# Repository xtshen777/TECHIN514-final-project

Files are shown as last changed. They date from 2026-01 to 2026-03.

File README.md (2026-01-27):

# Desk Emotion Indicator

## 1. Project overview

### Desk Emotion Indicator 
Cat-Ear Headband–based PPG Emotion Sensing System

### What it does  
The Desk Emotion Indicator is a two device system that uses a cat ear headband to measure heart related signals at the temples and a desk display with a mechanical gauge needle to visualize emotional trends from relaxed to stressed. The system is designed for desk based study or work, giving a calm and glanceable reflection of emotional state rather than exact numbers.

### General Sketch  
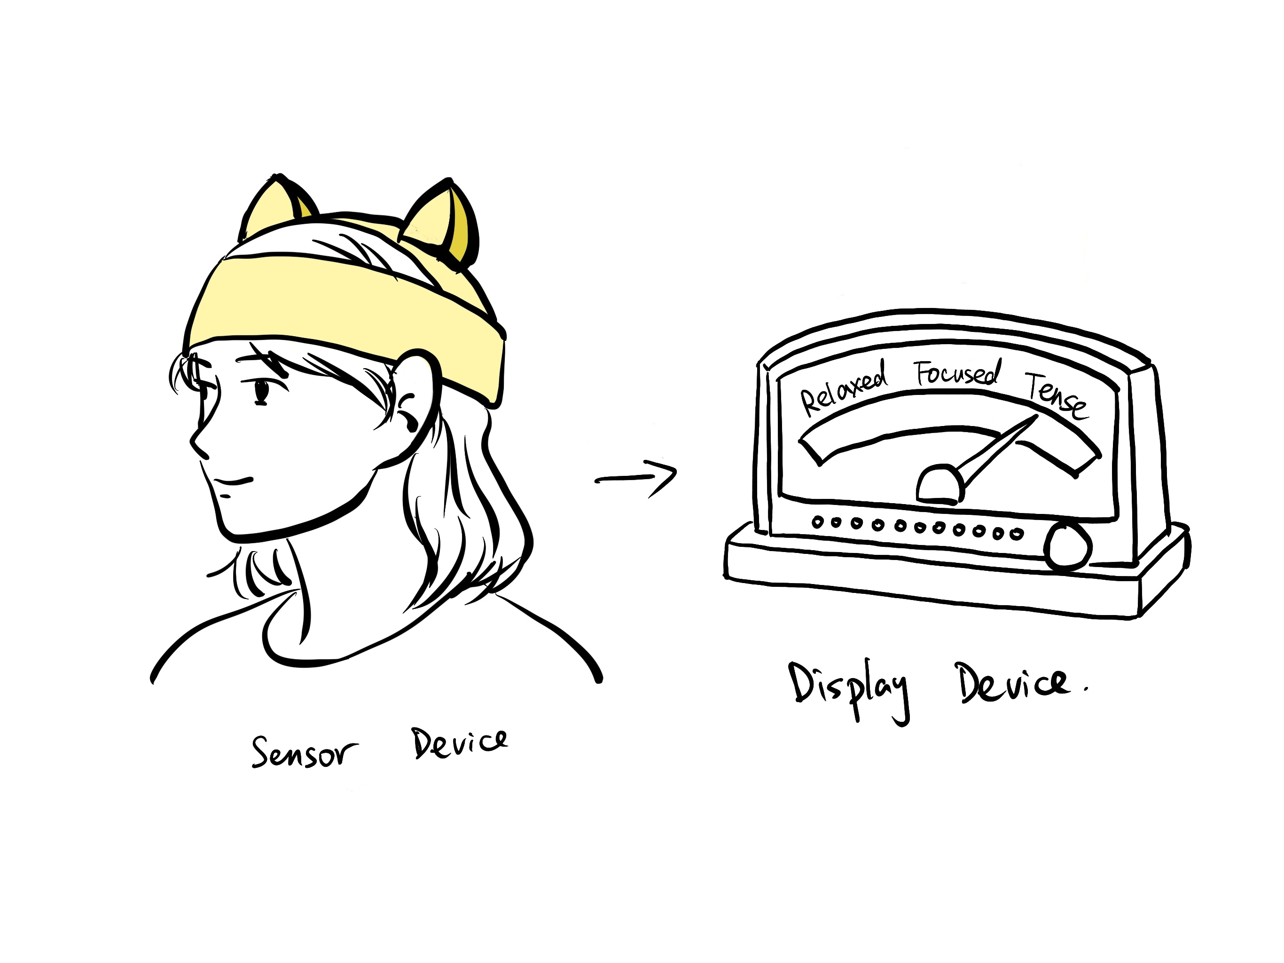
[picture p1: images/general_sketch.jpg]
Personal Safety Detector & Alarm Sketch

The sensing device is a cat shaped headband with two wide side sections that gently cover and touch the temple areas. A PPG sensor module is embedded inside each wide section so that the optical window rests against the skin, with soft foam pads and light blocking rings for comfort and signal quality. The cat ears on top of the headband are slightly thickened and used to hide the PCB, ESP32 based microcontroller and battery, as well as to route and organize the sensor wiring.

The display device is a small desk unit that looks like a vintage analog meter. It has a mechanical gauge needle driven by a stepper motor to show a continuous emotional state from relaxed to tense, a row of LEDs below the gauge as a secondary indication and a single reset or acknowledge button. The desk unit receives processed heart rate features wirelessly from the headband and updates the gauge and LEDs smoothly.

---

## 2. Sensor device (cat ear headband)

### Concept and placement  
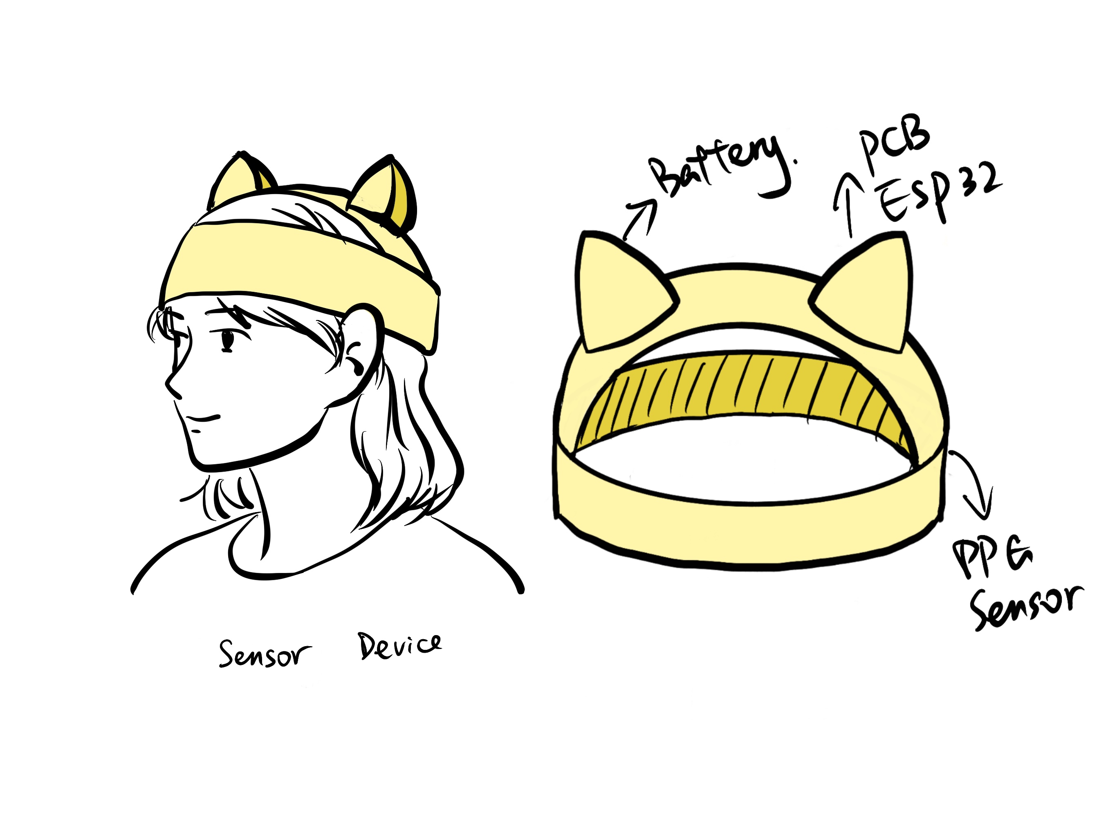
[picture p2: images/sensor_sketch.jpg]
Sensor Device

The sensor device is a cat ear headband that integrates PPG sensing modules at the temple positions. The headband sides are widened in the region that covers the temples to create space for the PPG boards and to provide a larger, more comfortable contact surface. On the inner side, soft foam pads and a small dark ring around each PPG window help maintain gentle pressure, reduce ambient light and improve signal quality. The cat ears on top of the headband are used as a functional enclosure that hides the main PCB, ESP32 module and battery, while also serving as a playful form language.

### Electronics and part numbers  
Planned parts for the sensor device include:

- Processor and wireless  
  - Seeed Studio XIAO ESP32C3 (ESP32 C3 based MCU with BLE)

- Optical heart sensor  
  - MAX30102 pulse oximeter and heart rate sensor module  
    - PPG sensing for heart rate and heart rate variability features  
  - Initially one MAX30102 module at one temple for prototyping, with the option to extend to both sides later

- Power  
  - 3.7 V LiPo battery, about 500 mAh  
  - TP4056 LiPo charger module  
  - Power switch

- Mechanical and wiring  
  - Cat ear headband shell with widened temple sections  
  - Soft foam or silicone pads around each sensor window  
  - Flexible wires routed inside the headband structure  
  - Custom small PCB in one cat ear that connects MAX30102, XIAO ESP32C3, battery and charger

### How it works  
The MAX30102 module in the temple section emits light into the skin and measures the reflected light signal that changes with blood volume. The Seeed XIAO ESP32C3 reads raw PPG samples over I2C, applies basic filtering and peak detection and computes heart rate and short term heart rate variability features over a sliding time window. Instead of sending raw signals, the headband computes compact emotional features such as smoothed heart rate and an HRV based stress score and periodically transmits these features via BLE to the desk display device. The headband is designed for stable contact during desk work, avoiding hand and wrist motion artifacts.

---

## 3. Display device (desk gauge)

### Concept and placement  
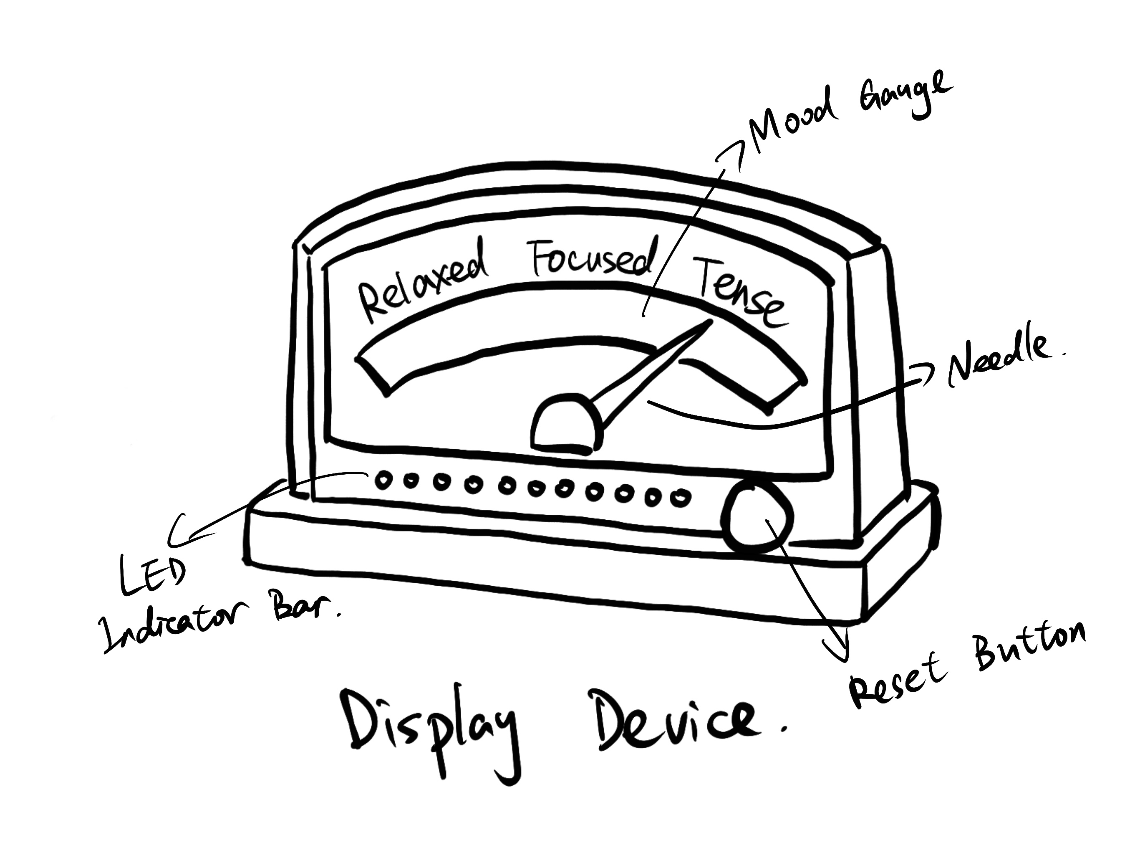
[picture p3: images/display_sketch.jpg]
Display Device

The display device is a compact desk unit that turns the incoming physiological features into a physical gauge and subtle light feedback. The main element is a mechanical needle gauge that moves smoothly between relaxed and stressed states. Below the gauge, a horizontal row of LEDs provides a secondary visualization that lights up more segments as the user becomes more tense. A single tactile button on the front allows the user to reset or acknowledge the current state or recalibrate the baseline.

### Electronics and part numbers  
Planned parts for the display device include:

- Processor and wireless  
  - Seeed Studio XIAO ESP32C3 (second board, acting as BLE central and display controller)

- Mechanical gauge  
  - 28BYJ 48 stepper motor  
  - ULN2003 stepper motor driver board

- Visual indicators  
  - LEDs, green, yellow and red or several identical color LEDs  
  - Current limiting resistors for each LED (for example 220 Ω to 330 Ω)

- User input  
  - One momentary tactile push button for reset or acknowledge

- Power  
  - 3.7 V LiPo battery, about 1000 mAh  
  - TP4056 LiPo charger module  
  - Power switch

- Mechanical  
  - Custom enclosure designed to sit on a desk and support the gauge dial  
  - Custom PCB that connects XIAO ESP32C3, ULN2003, LEDs, button and power components

### How it works  
The desk device acts as a BLE central and listens for periodic data packets from the headband sensor device. When it receives new heart rate and HRV based features, the XIAO ESP32C3 maps the emotional state score to a target gauge angle and LED pattern. The microcontroller drives the ULN2003 board to step the 28BYJ 48 motor to the new angle in a smooth way to avoid sudden jumps. The LEDs under the gauge are updated to indicate low, medium or high stress zones. The reset button allows the user to set a new baseline or clear a previously high state. The display is intentionally quiet and uses only motion and soft light to keep the feedback calm and ambient.

---

## 4. System communication and diagrams

### 4.1 High level system diagram
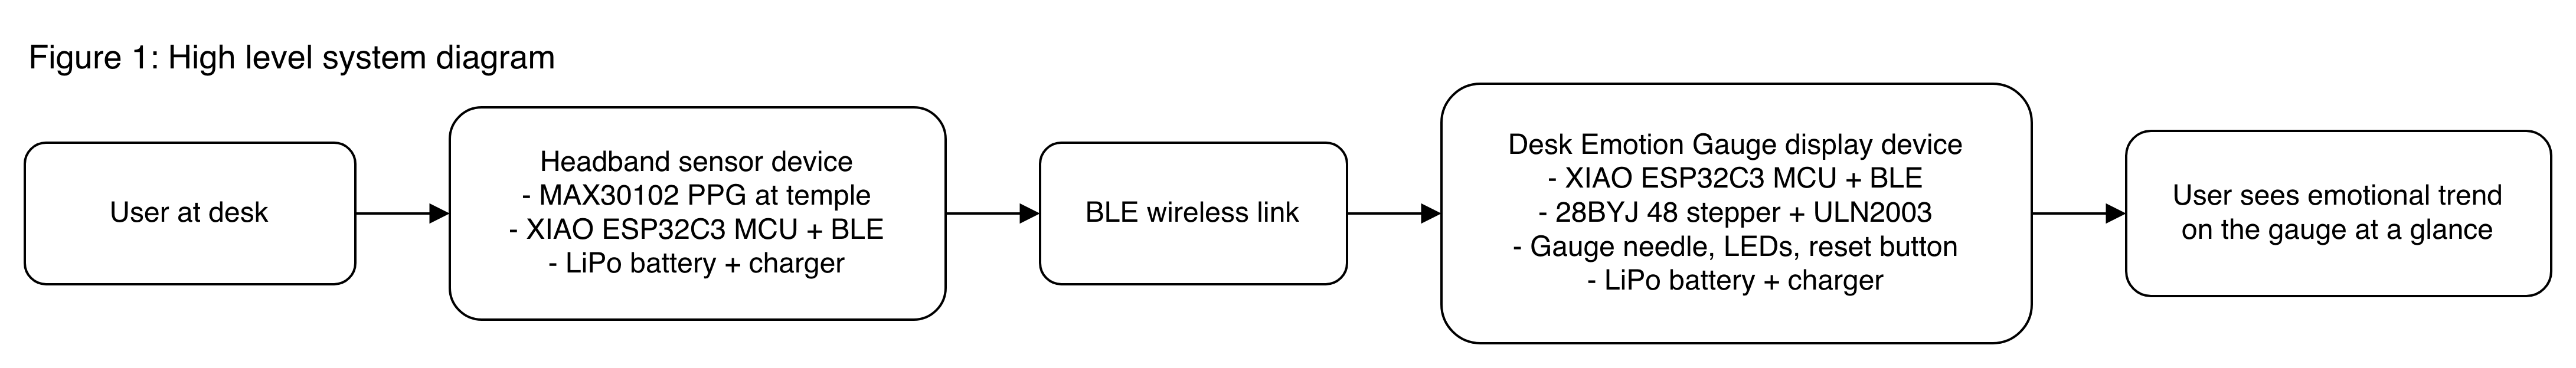
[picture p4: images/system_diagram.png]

- User sitting at a desk wearing the cat ear headband  
- The cat ear headband labeled as "Sensor device" with temple based PPG sensing  
- The desk gauge unit labeled as "Display device" with needle, LEDs and button  
- A BLE wireless link between headband and desk gauge  

### 4.2 Detailed data flow diagram (figure 2)
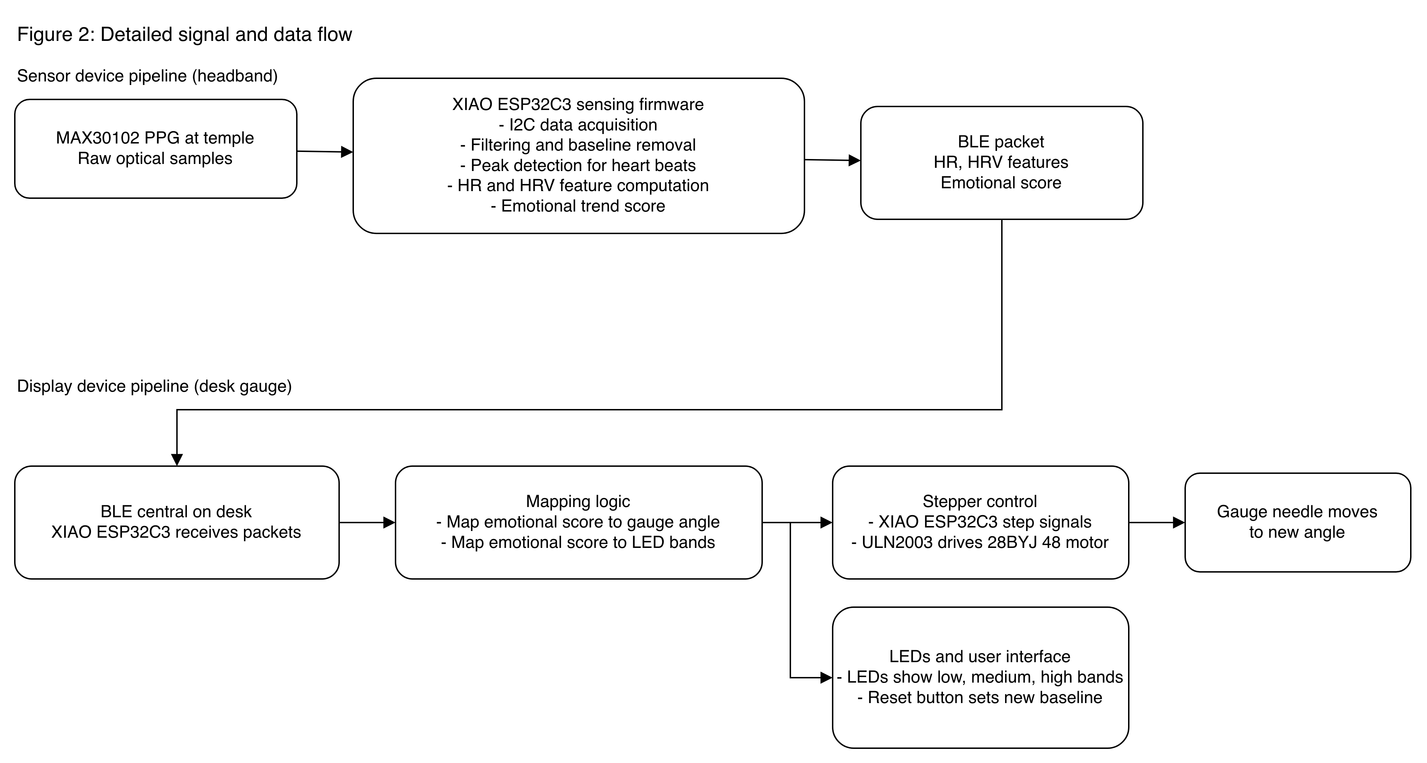
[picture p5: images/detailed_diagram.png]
 

Sensor device pipeline (headband):

- MAX30102 PPG module at temple  
  - Raw optical signal samples  
- XIAO ESP32C3 sensing firmware  
  - I2C data acquisition  
  - Filtering and baseline removal  
  - Peak detection for heart beats  
  - Heart rate and HRV feature computation  
  - Emotional trend score calculation  
- BLE packet  
  - Contains heart rate, HRV features and an emotional score  

Display device pipeline (desk gauge):

- BLE central on desk XIAO ESP32C3  
  - Receives packets from the headband  
- Mapping logic  
  - Map emotional score to gauge angle range  
  - Map emotional score to LED band states  
- Stepper control  
  - XIAO ESP32C3 generates step signals  
  - ULN2003 driver powers 28BYJ 48 motor  
  - Gauge needle moves to new angle  
- LED and user interface  
  - LEDs show low, medium or high emotional bands  
  - User can press the reset button to set a new baseline or acknowledge a high state  

---

## 5. Datasheets

All component datasheets used in this project are available in the `datasheets/` folder:

- [Seeed XIAO ESP32C3](datasheets/Seeed_XIAO_ESP32C3.pdf)
- [MAX30102 PPG Sensor](datasheets/MAX30102_sensor.pdf)
- [28BYJ-48 Stepper Motor](datasheets/28BYJ48_stepper_motor.pdf)
- [ULN2003 Driver](datasheets/ULN2003_driver.pdf)
- [TP4056 Charger](datasheets/TP4056_charger.pdf)
- [LiPo Battery](datasheets/LiPo_battery.pdf)
- [Tactile Switch](datasheets/tactile_switch.pdf)
- [NeoPixel Digital RGB LED Strip](datasheets/NeoPixel_LED.pdf)

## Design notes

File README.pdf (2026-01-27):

README.md | 2026-01-26

# Desk Emotion Indicator

## 1. Project overview

Desk Emotion Indicator

Cat-Ear Headband–based PPG Emotion Sensing System

What it does

The Desk Emotion Indicator is a two device system that uses a cat ear headband to measure heart related signals at the temples and a desk display with a mechanical gauge needle to visualize emotional trends from relaxed to stressed. The system is designed for desk based study or work, giving a calm and glanceable reflection of emotional state rather than exact numbers.

General Sketch


The sensing device is a cat shaped headband with two wide side sections that gently cover and touch the temple areas. A PPG sensor module is embedded inside each wide section so that the optical window rests against the skin, with soft foam pads and light blocking rings for comfort and signal quality. The cat ears on top of the headband are slightly thickened and used to hide the PCB, ESP32 based microcontroller and battery, as well as to route and organize the sensor wiring.

The display device is a small desk unit that looks like a vintage analog meter. It has a mechanical gauge needle driven by a stepper motor to show a continuous emotional state from relaxed to tense, a row of LEDs below the gauge as a secondary indication and a single reset or acknowledge button. The desk unit receives processed heart rate features wirelessly from the headband and updates the gauge and LEDs smoothly.

## 2. Sensor device (cat ear headband)

Concept and placement


The sensor device is a cat ear headband that integrates PPG sensing modules at the temple positions. The headband sides are widened in the region that covers the temples to create space for the PPG boards and to provide a larger, more comfortable contact surface. On the inner side, soft foam pads and a small dark ring around each PPG window help maintain gentle pressure, reduce ambient light and improve signal quality. The cat ears on top of the headband are used as a functional enclosure that hides the main PCB, ESP32 module and battery, while also serving as a playful form language.

Electronics and part numbers

Planned parts for the sensor device include:

Processor and wireless

Seeed Studio XIAO ESP32C3 (ESP32 C3 based MCU with BLE)

Optical heart sensor

MAX30102 pulse oximeter and heart rate sensor module
PPG sensing for heart rate and heart rate variability features
Initially one MAX30102 module at one temple for prototyping, with the option to extend to both sides later

Power

3.7 V LiPo battery, about 500 mAh TP4056 LiPo charger module Power switch

Mechanical and wiring

Cat ear headband shell with widened temple sections
Soft foam or silicone pads around each sensor window
Flexible wires routed inside the headband structure
Custom small PCB in one cat ear that connects MAX30102, XIAO ESP32C3, battery and charger

How it works

The MAX30102 module in the temple section emits light into the skin and measures the reflected light signal that changes with blood volume. The Seeed XIAO ESP32C3 reads raw PPG samples over I2C, applies basic filtering and peak detection and computes heart rate and short term heart rate variability features over a sliding time window. Instead of sending raw signals, the headband computes compact emotional features such as smoothed heart rate and an HRV based stress score and periodically transmits these features via BLE to the desk display device. The headband is designed for stable contact during desk work, avoiding hand and wrist motion artifacts.

## 3. Display device (desk gauge)

Concept and placement


The display device is a compact desk unit that turns the incoming physiological features into a physical gauge and subtle light feedback. The main element is a mechanical needle gauge that moves smoothly between relaxed and stressed states. Below the gauge, a horizontal row of LEDs provides a secondary visualization that lights up more segments as the user becomes more tense. A single tactile button on the front allows the user to reset or acknowledge the current state or recalibrate the baseline.

Electronics and part numbers

Planned parts for the display device include:

Processor and wireless

Seeed Studio XIAO ESP32C3 (second board, acting as BLE central and display controller)

Mechanical gauge

28BYJ 48 stepper motor
ULN2003 stepper motor driver board

Visual indicators

LEDs, green, yellow and red or several identical color LEDs
Current limiting resistors for each LED (for example 220 Ω to 330 Ω)

User input

One momentary tactile push button for reset or acknowledge

Power

3.7 V LiPo battery, about 1000 mAh
TP4056 LiPo charger module Power switch

Mechanical

Custom enclosure designed to sit on a desk and support the gauge dial
Custom PCB that connects XIAO ESP32C3, ULN2003, LEDs, button and power components

How it works

The desk device acts as a BLE central and listens for periodic data packets from the headband sensor device. When it receives new heart rate and HRV based features, the XIAO ESP32C3 maps the emotional state score to a target gauge angle and LED pattern. The microcontroller drives the ULN2003 board to step the 28BYJ 48 motor to the new angle in a smooth way to avoid sudden jumps. The LEDs under the gauge are updated to indicate low, medium or high stress zones. The reset button allows the user to set a new baseline or clear a previously high state. The display is intentionally quiet and uses only motion and soft light to keep the feedback calm and ambient.

## 4. System communication and diagrams

4.1 High level system diagram

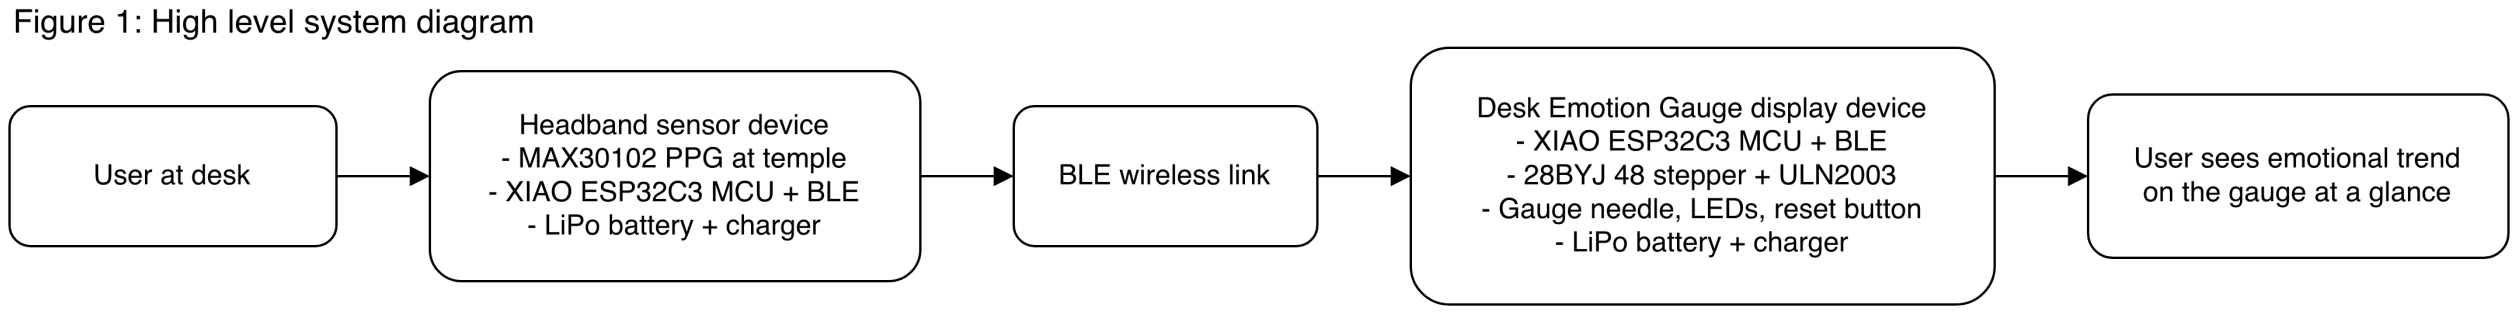
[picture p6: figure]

User sitting at a desk wearing the cat ear headband
The cat ear headband labeled as "Sensor device" with temple based PPG sensing The desk gauge unit labeled as "Display device" with needle, LEDs and button
A BLE wireless link between headband and desk gauge

4.2 Detailed data flow diagram (figure 2)

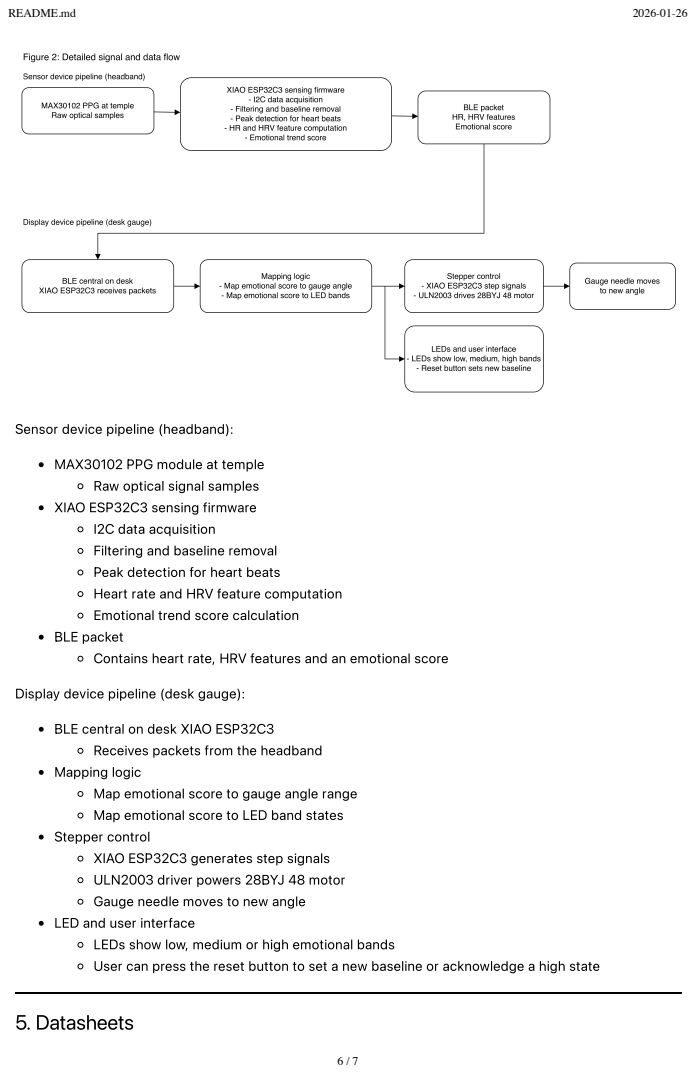
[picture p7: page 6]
5. Datasheets

Sensor device pipeline (headband):

MAX30102 PPG module at temple
Raw optical signal samples
XIAO ESP32C3 sensing firmware
I2C data acquisition
Filtering and baseline removal
Peak detection for heart beats
Heart rate and HRV feature computation
Emotional trend score calculation
BLE packet
Contains heart rate, HRV features and an emotional score

Display device pipeline (desk gauge):

BLE central on desk XIAO ESP32C3
Receives packets from the headband
Mapping logic
Map emotional score to gauge angle range
Map emotional score to LED band states
Stepper control
XIAO ESP32C3 generates step signals
ULN2003 driver powers 28BYJ 48 motor
Gauge needle moves to new angle
LED and user interface
LEDs show low, medium or high emotional bands
User can press the reset button to set a new baseline or acknowledge a high state

All component datasheets used in this project are available in the datasheets/ folder:

Seeed XIAO ESP32C3
MAX30102 PPG Sensor
28BYJ-48 Stepper Motor
ULN2003 Driver
TP4056 Charger
LiPo Battery
Tactile Switch
NeoPixel Digital RGB LED Strip

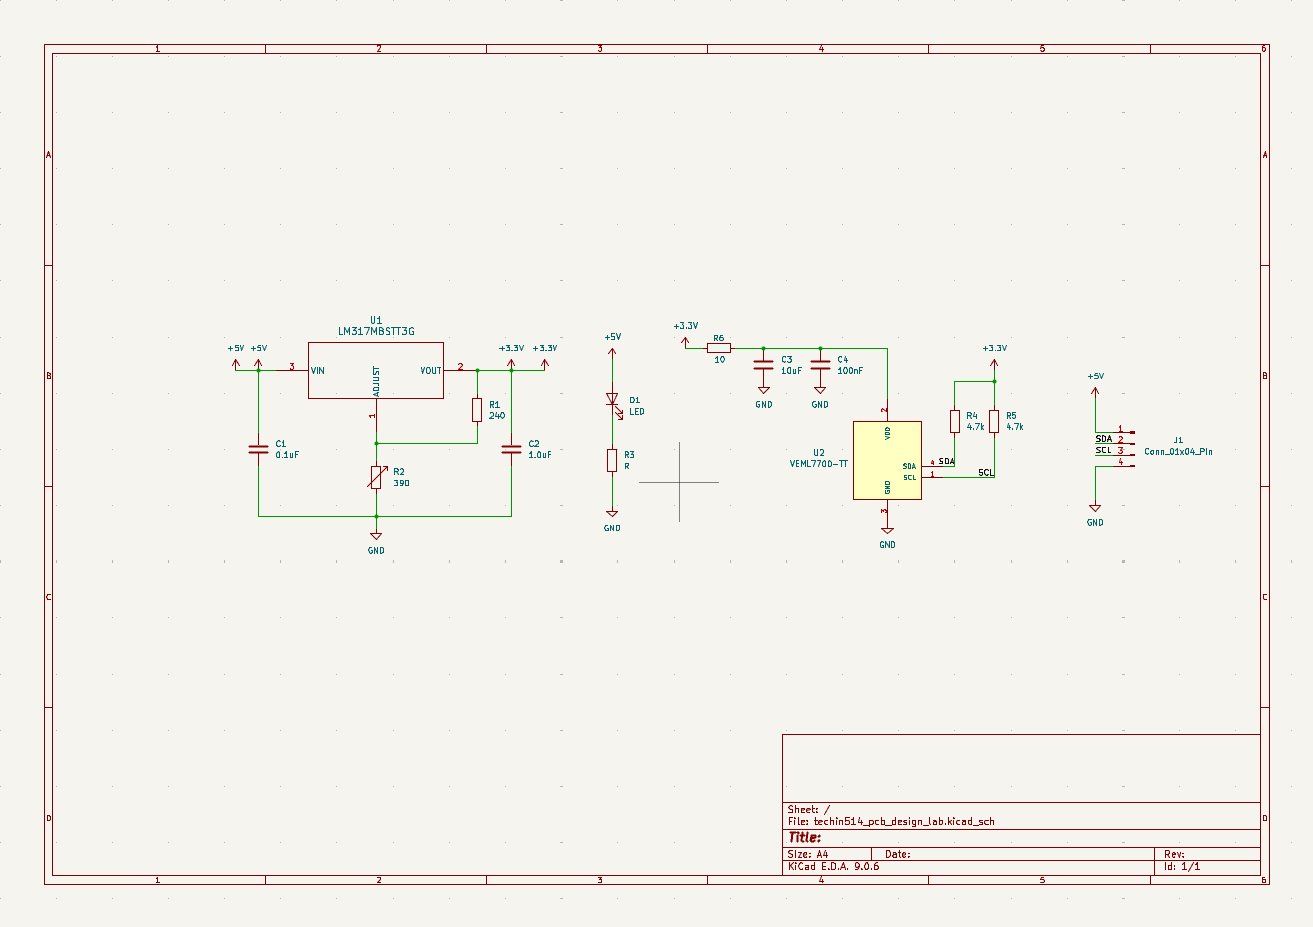
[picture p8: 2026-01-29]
pcb_lab/schematics.png

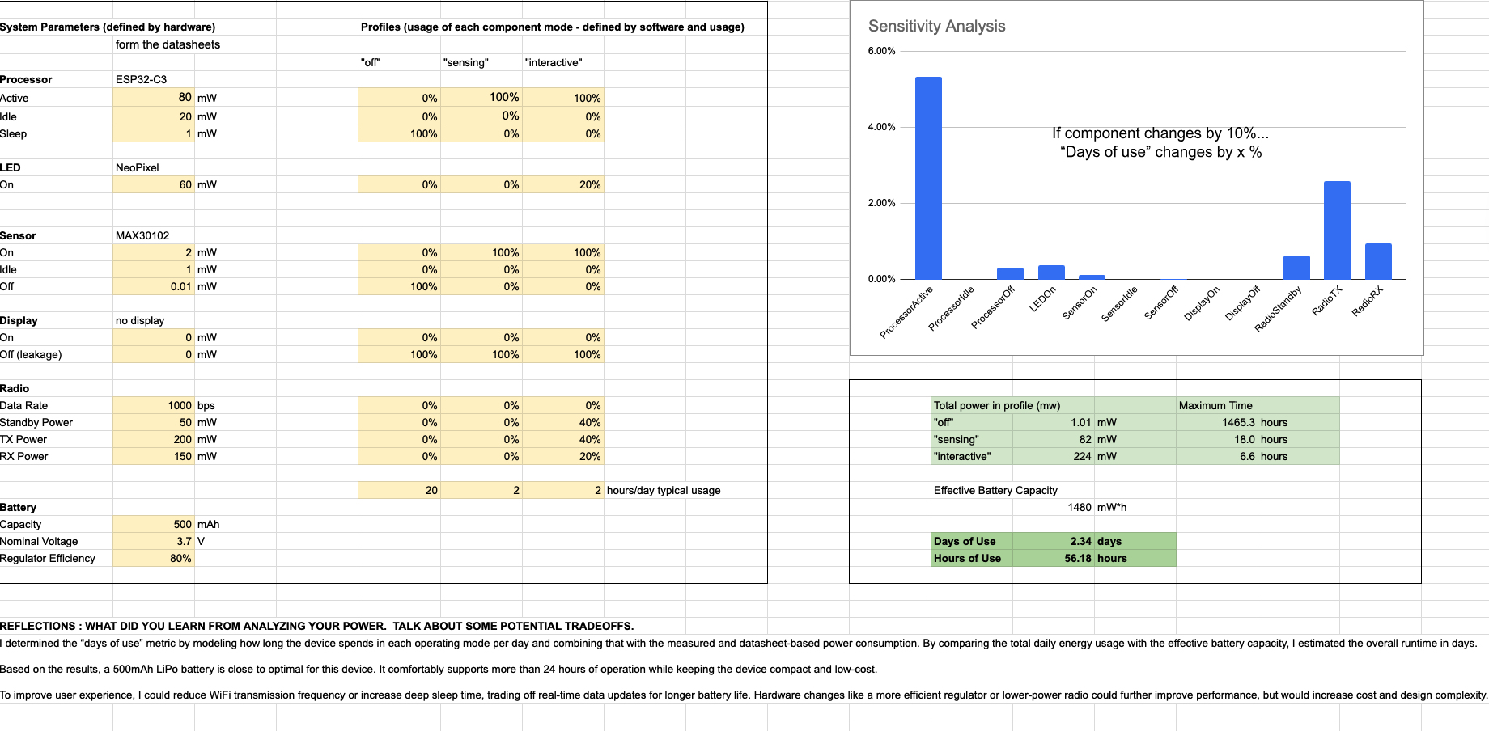
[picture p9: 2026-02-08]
battery_life_estimate/spreadsheet.png

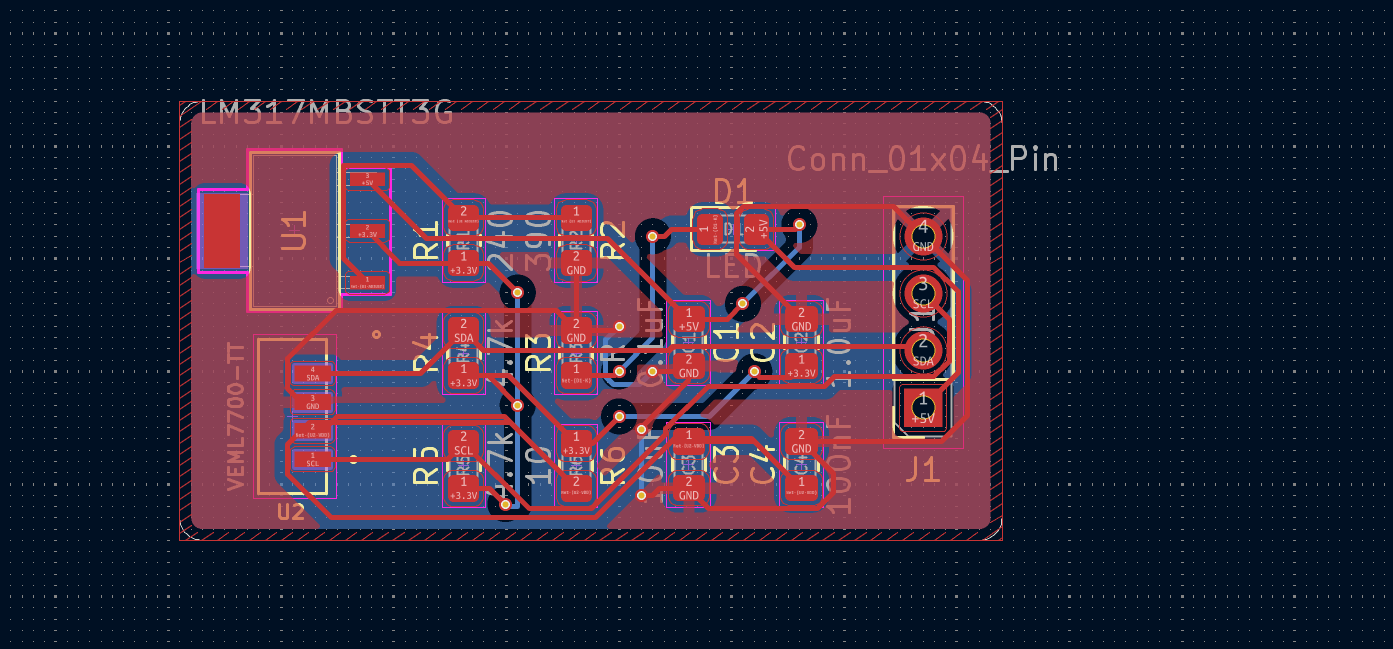
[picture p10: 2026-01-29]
pcb_lab/board layout.png

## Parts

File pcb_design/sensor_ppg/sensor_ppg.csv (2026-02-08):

# | Reference | Qty | Value | Footprint | DNP
1 | C1 | 1 | 10uF | Capacitor_SMD:C_0603_1608Metric_Pad1.08x0.95mm_HandSolder
2 | C2, C4 | 2 | 0.1uF | Capacitor_SMD:C_0603_1608Metric_Pad1.08x0.95mm_HandSolder
3 | C3 | 1 | 4.7uF | Capacitor_SMD:C_0603_1608Metric_Pad1.08x0.95mm_HandSolder
4 | C5, C6 | 2 | 1uF | Capacitor_SMD:C_0603_1608Metric_Pad1.08x0.95mm_HandSolder
5 | J1 | 1 | Conn_01x07_Pin | Connector_PinSocket_2.54mm:PinSocket_1x07_P2.54mm_Vertical
6 | R1, R2, R3 | 3 | 4.7kΩ | Resistor_SMD:R_0603_1608Metric_Pad0.98x0.95mm_HandSolder
7 | U1 | 1 | MAX30102EFD_T | MAX30102EFD_T:XDCR_MAX30101EFD_
8 | U2 | 1 | MIC5365-1.8YMT-TZ | MIC5365_1_8YMT_TZ_snap:VREG_MIC5365-1.8YMT-TZ

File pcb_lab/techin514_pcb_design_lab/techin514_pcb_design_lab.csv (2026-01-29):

# | Reference | Qty | Value | Footprint | DNP
1 | C1 | 1 | 0.1uF | Capacitor_SMD:C_0805_2012Metric_Pad1.18x1.45mm_HandSolder
2 | C2 | 1 | 1.0uF | Capacitor_SMD:C_0805_2012Metric_Pad1.18x1.45mm_HandSolder
3 | C3 | 1 | 10uF | Capacitor_SMD:C_0805_2012Metric_Pad1.18x1.45mm_HandSolder
4 | C4 | 1 | 100nF | Capacitor_SMD:C_0805_2012Metric_Pad1.18x1.45mm_HandSolder
5 | D1 | 1 | LED | LED_SMD:LED_0805_2012Metric_Pad1.15x1.40mm_HandSolder
6 | J1 | 1 | Conn_01x04_Pin | Connector_PinSocket_2.54mm:PinSocket_1x04_P2.54mm_Vertical
7 | R1 | 1 | 240 | Resistor_SMD:R_0805_2012Metric_Pad1.20x1.40mm_HandSolder
8 | R2 | 1 | 390 | Resistor_SMD:R_0805_2012Metric_Pad1.20x1.40mm_HandSolder
9 | R3 | 1 | R | Resistor_SMD:R_0805_2012Metric_Pad1.20x1.40mm_HandSolder
10 | R4, R5 | 2 | 4.7k | Resistor_SMD:R_0805_2012Metric_Pad1.20x1.40mm_HandSolder
11 | R6 | 1 | 10 | Resistor_SMD:R_0805_2012Metric_Pad1.20x1.40mm_HandSolder
12 | U1 | 1 | LM317MBSTT3G | footprints:SOT223-3_ONS
13 | U2 | 1 | VEML7700-TT | VEML7700_TT:XDCR_VEML7700-TT

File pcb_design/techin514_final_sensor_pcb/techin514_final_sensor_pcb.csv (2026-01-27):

# | Reference | Qty | Value | Footprint | DNP
1 | C1, C2, C3 | 3 | C
2 | D1 | 1 | LED
3 | D2 | 1 | NeoPixel Digital RGB LED | LED_SMD:LED_WS2812_PLCC6_5.0x5.0mm_P1.6mm
4 | M1 | 1 | Stepper_Motor_bipolar
5 | R1, R2, R3, R4, R5, R6 | 6 | R
6 | S1 | 1 | SWITCH
7 | U1 | 1 | MAX30102 | OptoDevice:Maxim_OLGA-14_3.3x5.6mm_P0.8mm
8 | U2 | 1 | MOUDLE-SEEEDUINO-XIAO-ESP32C3 | MOUDLE14P-SMD-2.54-21X17.8MM
9 | U3 | 1 | ULN2003
10 | U4 | 1 | LM317L_SOT-89 | Package_TO_SOT_SMD:SOT-89-3

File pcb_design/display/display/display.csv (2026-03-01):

# | Reference | Qty | Value | Footprint | DNP
1 | C1 | 1 | 10uF | Capacitor_SMD:C_0805_2012Metric_Pad1.18x1.45mm_HandSolder
2 | C2 | 1 | 0.01uF | Capacitor_SMD:C_0805_2012Metric_Pad1.18x1.45mm_HandSolder
3 | C3 | 1 | 2.2uF | Capacitor_SMD:C_0805_2012Metric_Pad1.18x1.45mm_HandSolder
4 | C4 | 1 | 100uF | Capacitor_SMD:C_0805_2012Metric_Pad1.18x1.45mm_HandSolder
5 | J1 | 1 | Conn_01x03 | Connector_JST:JST_PH_B3B-PH-K_1x03_P2.00mm_Vertical
6 | J2 | 1 | Conn_01x02 | Connector_JST:JST_PH_B2B-PH-K_1x02_P2.00mm_Vertical
7 | M1 | 1 | Stepper_Motor_bipolar | x27_Footprint:x27_stepper_two_holes
8 | R1, R2 | 2 | 0.2Ω | Resistor_SMD:R_0805_2012Metric_Pad1.20x1.40mm_HandSolder
9 | R3 | 1 | 330Ω | Resistor_SMD:R_0805_2012Metric_Pad1.20x1.40mm_HandSolder
10 | R4 | 1 | 10 kΩ | Resistor_SMD:R_0805_2012Metric_Pad1.20x1.40mm_HandSolder
11 | U1 | 1 | DRV8833PWR | DRV8833PWR:PW16_TEX-L
12 | U2 | 1 | XIAO ESP32C3 | GIX_ESP32:XIAO_ESP32

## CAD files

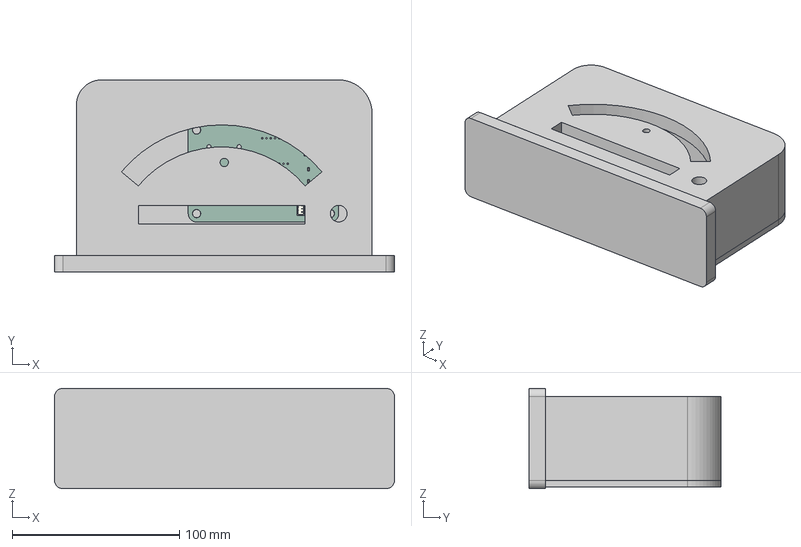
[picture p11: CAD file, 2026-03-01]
enclosure/display.step
203.4 x 115.0 x 60.0 mm
R_0805_2012Metric x 4
C_0805_2012Metric x 4
JST_PH_B3B-PH-K_1x03_P2.00mm_Vertical
JST_PH_B2B-PH-K_1x02_P2.00mm_Vertical
display_PCB

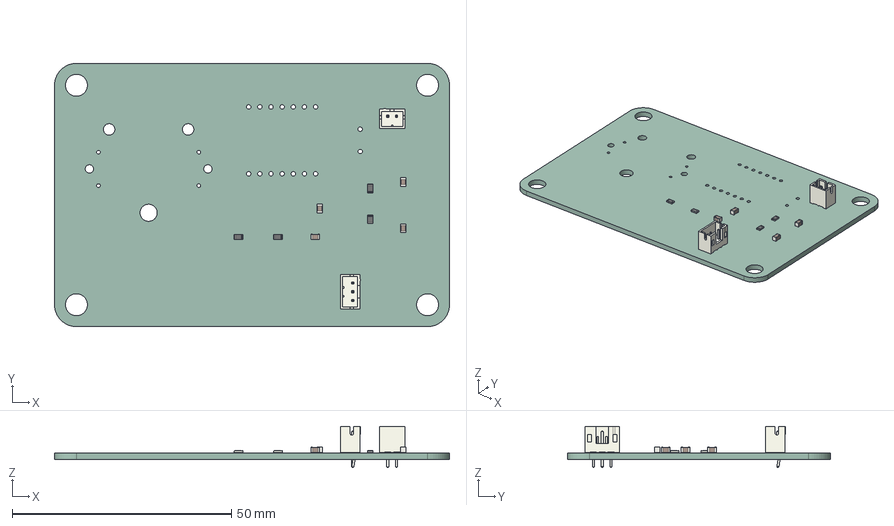
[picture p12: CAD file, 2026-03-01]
pcb_design/display/display/display.step
90.0 x 60.0 x 9.40 mm
R_0805_2012Metric x 4
C_0805_2012Metric x 4
JST_PH_B3B-PH-K_1x03_P2.00mm_Vertical
JST_PH_B2B-PH-K_1x02_P2.00mm_Vertical
display_PCB

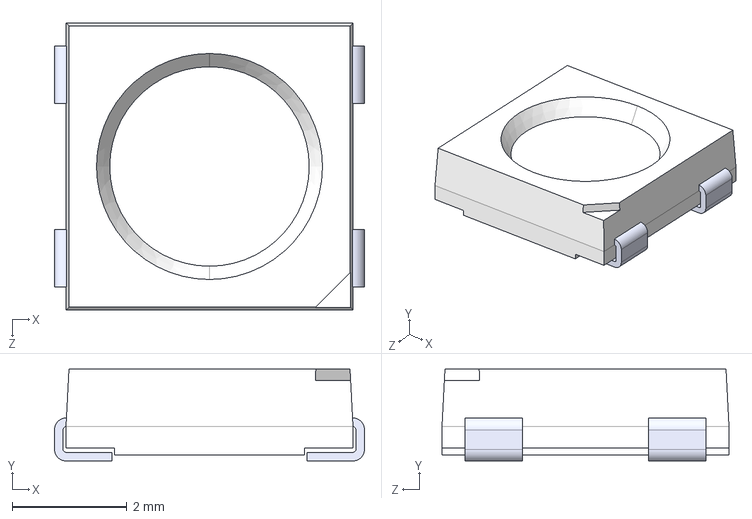
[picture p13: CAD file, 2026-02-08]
pcb_design/models/1655/1655.step
5.40 x 1.60 x 5.00 mm

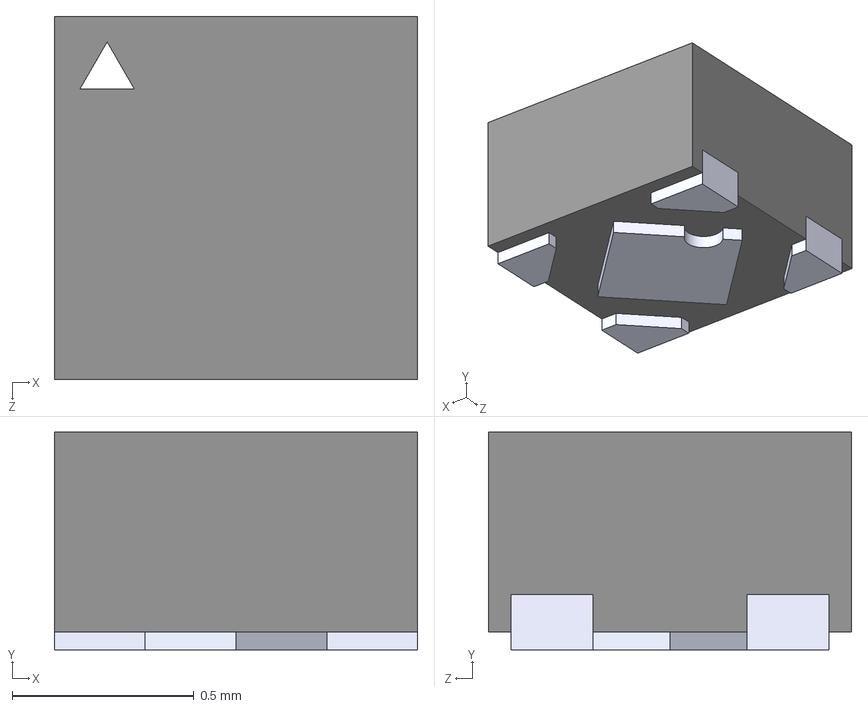
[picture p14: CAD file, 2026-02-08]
pcb_design/models/MIC5365_1_8YMT_TZ_snap/MIC5365-1.8YMT-TZ.step
1.00 x 0.6 x 1.00 mm

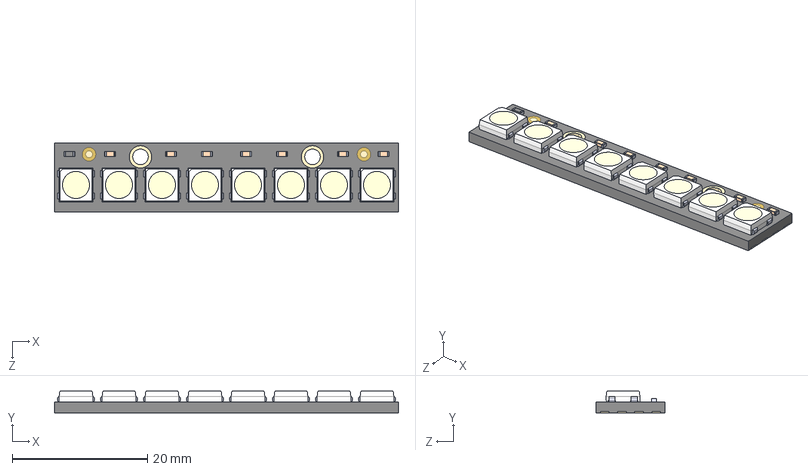
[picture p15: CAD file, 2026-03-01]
pcb_design/models/neopixel1426/1426.step
50.8 x 3.19 x 10.2 mm
1426 board
WS2812B--3DModel-STEP-510211 x 8
CAP_black
CAP_RC0603JR-073K3P x 7

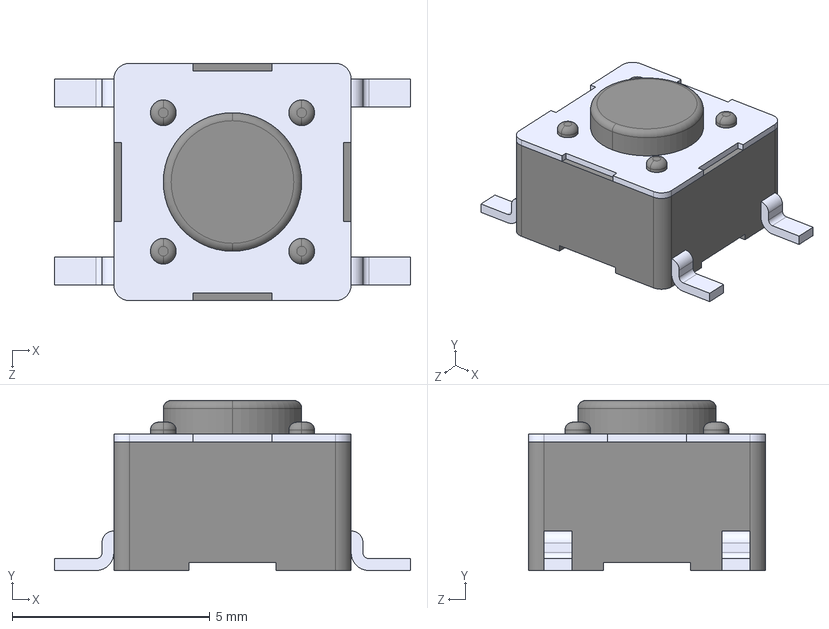
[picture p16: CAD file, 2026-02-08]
pcb_design/models/PTS645SK43SMTR92_LFS/PTS645SK43SMTR92LFS.step
9.00 x 4.30 x 6.00 mm

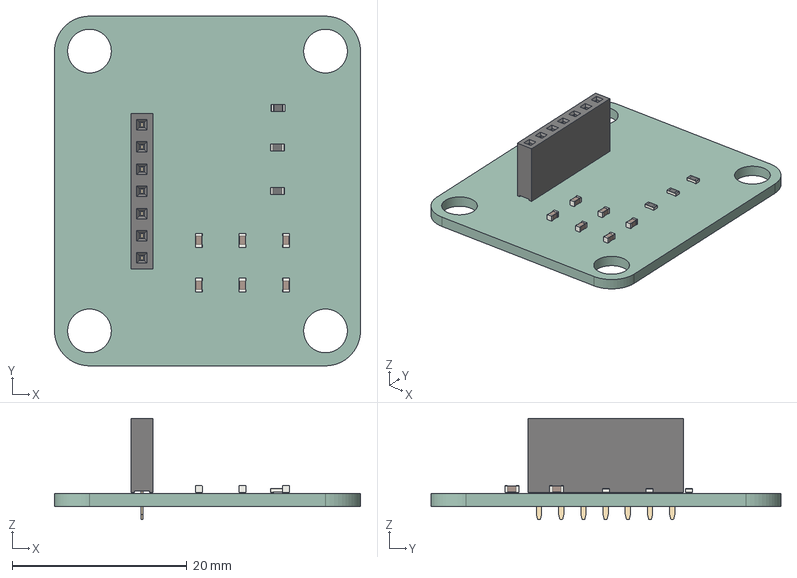
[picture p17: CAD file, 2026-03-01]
pcb_design/sensor_ppg/sensor_ppg.step
35.0 x 40.0 x 11.6 mm
C_0603_1608Metric x 6
R_0603_1608Metric x 3
PinSocket_1x07_P2.54mm_Vertical
sensor_ppg_PCB

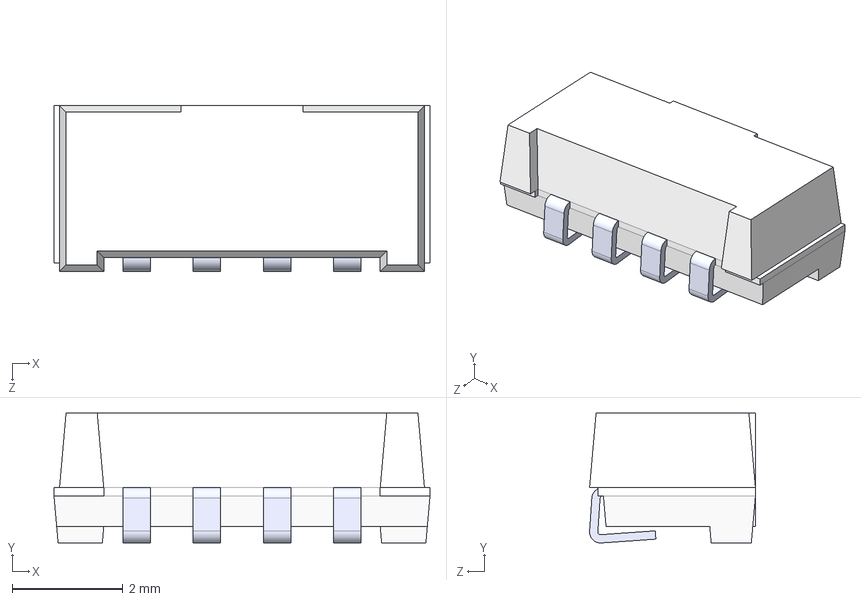
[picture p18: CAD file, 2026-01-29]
pcb_lab/footprint/VEML7700_TT/VEML7700-TT.step
6.80 x 2.35 x 3.00 mm

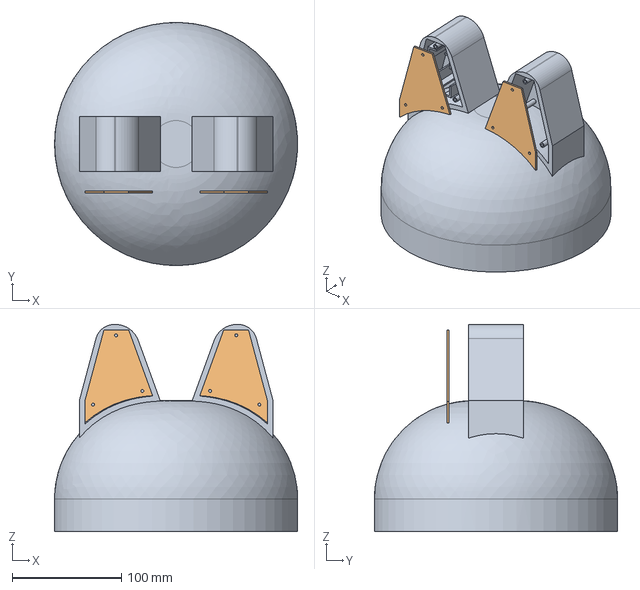
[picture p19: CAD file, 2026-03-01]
enclosure/head_sensor.step
222.8 x 222.9 x 190.0 mm

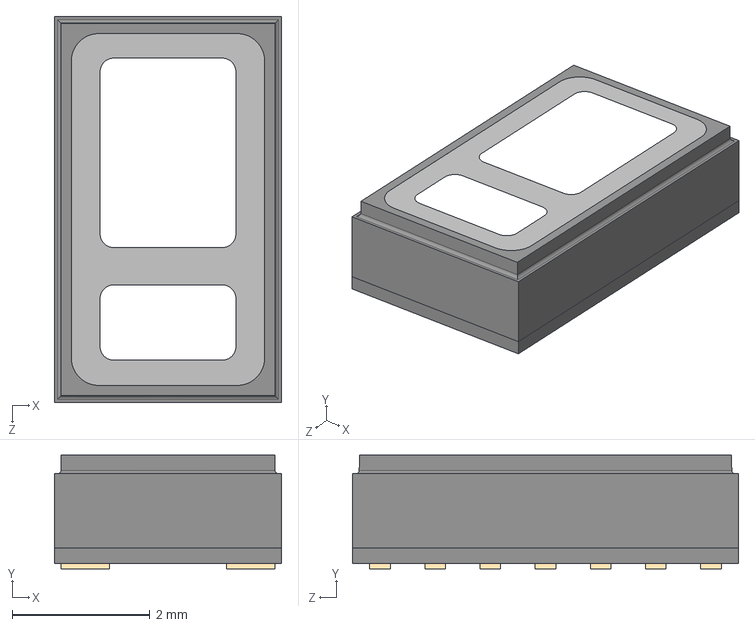
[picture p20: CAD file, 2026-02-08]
pcb_design/models/MAX30102EFD_T/MAX30102EFD_T.step
3.30 x 1.65 x 5.60 mm

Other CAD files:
enclosure/display.f3d
enclosure/head_sesnor.f3d
pcb_design/display/display/display.stl
pcb_design/sensor_ppg/sensor_ppg.stl

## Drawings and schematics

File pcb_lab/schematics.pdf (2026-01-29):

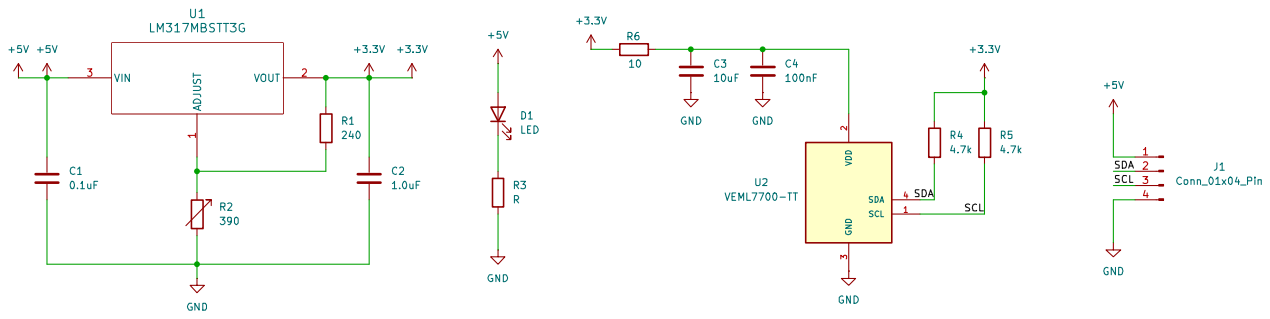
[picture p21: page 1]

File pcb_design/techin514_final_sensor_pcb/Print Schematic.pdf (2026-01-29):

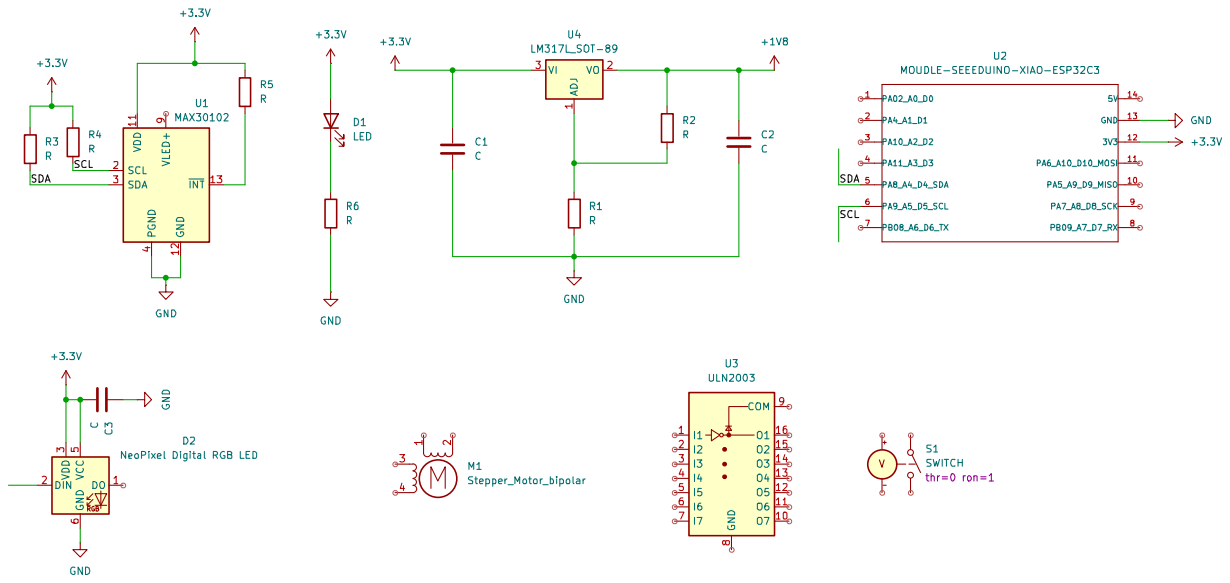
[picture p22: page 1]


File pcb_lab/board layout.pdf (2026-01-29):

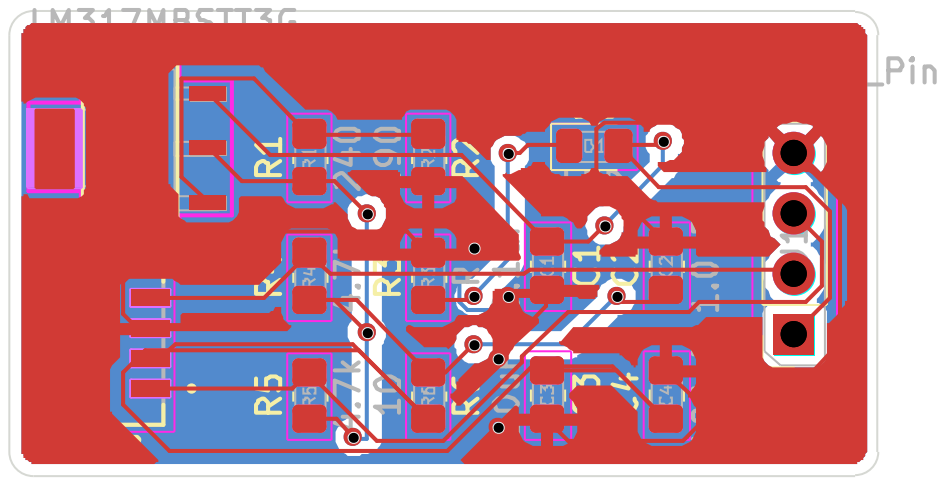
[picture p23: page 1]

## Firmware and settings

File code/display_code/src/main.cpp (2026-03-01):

#include <Arduino.h>

#include <Adafruit_NeoPixel.h>

// Pin configuration

// Stepper motor pins (X27 four wires)
// Use D0, D1, D2, D3 as on your schematic
const int MOTOR_PIN_A = 0;
const int MOTOR_PIN_B = 1;
const int MOTOR_PIN_C = 2;
const int MOTOR_PIN_D = 3;

// NeoPixel LED strip
const int LED_PIN      = 8;     // data pin for NeoPixel bar
const int LED_COUNT    = 8;

// Reset button
const int BUTTON_PIN   = 9;     // external 10k pullup to 3V3, active low

// Stepper configuration 

// Logical full scale for X27 pointer
const int STEPPER_MAX_STEPS = 600;
const int STEPPER_MIN_STEPS = 0;

// Simple 4 step sequence
const uint8_t STEPPER_SEQUENCE[4][4] = {
  {1, 0, 1, 0},
  {0, 1, 1, 0},
  {0, 1, 0, 1},
  {1, 0, 0, 1}
};

int currentStepIndex = 0;      // sequence index 0..3
int currentPosition  = 0;      // logical position 0..600
int targetPosition   = 0;      // desired position

unsigned long lastStepTime      = 0;
const unsigned long STEP_INTERVAL_MS = 5;   // adjust for motion speed

// NeoPixel configuration

Adafruit_NeoPixel strip(LED_COUNT, LED_PIN, NEO_GRB + NEO_KHZ800);

// Current heart rate
int currentHeartRateBpm = 0;

// Button debounce 

bool lastButtonState   = HIGH;
unsigned long lastDebounceTime = 0;
const unsigned long DEBOUNCE_DELAY_MS = 50;

// Heart rate mapping functions 

// Map heart rate to stepper logical position
int mapHeartRateToSteps(int bpm) {
  int minBpm = 50;
  int maxBpm = 150;

  if (bpm < minBpm) bpm = minBpm;
  if (bpm > maxBpm) bpm = maxBpm;

  float ratio = (float)(bpm - minBpm) / (float)(maxBpm - minBpm);
  int steps = STEPPER_MIN_STEPS + (int)(ratio * (STEPPER_MAX_STEPS - STEPPER_MIN_STEPS));
  return steps;
}

// Map heart rate to number of lit LEDs (0..LED_COUNT)
int mapHeartRateToLedCount(int bpm) {
  int minBpm = 50;
  int maxBpm = 150;

  if (bpm < minBpm) bpm = minBpm;
  if (bpm > maxBpm) bpm = maxBpm;

  float ratio = (float)(bpm - minBpm) / (float)(maxBpm - minBpm);
  int count = (int)round(ratio * LED_COUNT);
  if (count < 0) count = 0;
  if (count > LED_COUNT) count = LED_COUNT;
  return count;
}

// Stepper control 

void applyStepperCoils(int idx) {
  digitalWrite(MOTOR_PIN_A, STEPPER_SEQUENCE[idx][0]);
  digitalWrite(MOTOR_PIN_B, STEPPER_SEQUENCE[idx][1]);
  digitalWrite(MOTOR_PIN_C, STEPPER_SEQUENCE[idx][2]);
  digitalWrite(MOTOR_PIN_D, STEPPER_SEQUENCE[idx][3]);
}

void stepMotorOneStep(int direction) {
  if (direction > 0) {
    currentStepIndex = (currentStepIndex + 1) % 4;
    currentPosition++;
  } else if (direction < 0) {
    currentStepIndex = (currentStepIndex + 3) % 4;
    currentPosition--;
  }

  if (currentPosition < STEPPER_MIN_STEPS) currentPosition = STEPPER_MIN_STEPS;
  if (currentPosition > STEPPER_MAX_STEPS) currentPosition = STEPPER_MAX_STEPS;

  applyStepperCoils(currentStepIndex);
}

void updateStepper() {
  unsigned long now = millis();
  if (now - lastStepTime < STEP_INTERVAL_MS) {
    return;
  }

  lastStepTime = now;

  if (currentPosition < targetPosition) {
    stepMotorOneStep(+1);
  } else if (currentPosition > targetPosition) {
    stepMotorOneStep(-1);
  } else {
    // already at target
  }
}

// NeoPixel display 

// Gradient color, left light color, right deep color
uint32_t colorFromIndex(int index, int maxIndex) {
  float t = 0.0;
  if (maxIndex > 0) {
    t = (float)index / (float)maxIndex;
  }

  // light color on the left
  uint8_t r1 = 80,  g1 = 120, b1 = 255;
  // deep color on the right
  uint8_t r2 = 180, g2 = 0,   b2 = 200;

  uint8_t r = r1 + (uint8_t)((r2 - r1) * t);
  uint8_t g = g1 + (uint8_t)((g2 - g1) * t);
  uint8_t b = b1 + (uint8_t)((b2 - b1) * t);

  return strip.Color(r, g, b);
}

void updateLedBar(int bpm) {
  if (bpm <= 0) {
    // treat as reset: turn all off
    for (int i = 0; i < LED_COUNT; i++) {
      strip.setPixelColor(i, 0);
    }
    strip.show();
    return;
  }

  int litCount = mapHeartRateToLedCount(bpm);

  for (int i = 0; i < LED_COUNT; i++) {
    if (i < litCount) {
      uint32_t c = colorFromIndex(i, LED_COUNT - 1);
      strip.setPixelColor(i, c);
    } else {
      strip.setPixelColor(i, 0);
    }
  }
  strip.show();
}

// Reset behavior 

void resetDisplayState() {
  currentHeartRateBpm = 0;
  targetPosition      = STEPPER_MIN_STEPS;

  // move pointer gradually back to minimum
  // we let updateStepper handle it in loop
  updateLedBar(0);  // clear LED bar
}

// Heart rate update entry 

// This function is called whenever new heart rate data is received.
// Later you can call this from your BLE callback.
void onHeartRateReceived(int bpm) {
  currentHeartRateBpm = bpm;
  targetPosition      = mapHeartRateToSteps(bpm);
  updateLedBar(bpm);
}

// Setup and loop 

void setup() {
  Serial.begin(115200);

  // Stepper pins
  pinMode(MOTOR_PIN_A, OUTPUT);
  pinMode(MOTOR_PIN_B, OUTPUT);
  pinMode(MOTOR_PIN_C, OUTPUT);
  pinMode(MOTOR_PIN_D, OUTPUT);
  applyStepperCoils(0);

  // Button
  pinMode(BUTTON_PIN, INPUT);   // external pullup to 3V3

  // NeoPixel
  strip.begin();
  strip.setBrightness(80);      // adjust brightness if needed
  strip.show();                 // clear all LEDs

  // Placeholder: Initialize BLE and set up heart rate callback

  resetDisplayState();
}

void loop() {
  // 1. Stepper follows target position
  updateStepper();

  // 2. Reset button check (active low)
  int reading = digitalRead(BUTTON_PIN);
  if (reading != lastButtonState) {
    lastDebounceTime = millis();
    lastButtonState = reading;
  }

  if ((millis() - lastDebounceTime) > DEBOUNCE_DELAY_MS) {
    if (reading == LOW) {
      // button pressed
      resetDisplayState();
      // small delay to avoid repeated triggers
      delay(300);
    }
  }

  // 3. Temporary simulation for testing without BLE
  // Uncomment this block to see pointer and LED respond.
  /*
  static unsigned long lastSimTime = 0;
  static int fakeBpm = 60;
  if (millis() - lastSimTime > 1000) {
    lastSimTime = millis();
    fakeBpm += 5;
    if (fakeBpm > 140) fakeBpm = 60;
    onHeartRateReceived(fakeBpm);
    Serial.print("Simulated BPM: ");
    Serial.println(fakeBpm);
  }
  */
}

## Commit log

2026-01-27 update on pcb sch and bom
    [techin514_final_sensor_pcb.csv, techin514_final_sensor_pcb.kicad_pcb, techin514_final_sensor_pcb.kicad_sch]
2026-01-29 update pcd design lab
    [VEML7700-TT.step, techin514_pcb_design_lab.csv, techin514_pcb_design_lab.kicad_pcb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]
2026-01-29 update schematics and layout
2026-02-08 battery life estimate
    [1655.step, MAX30102EFD_T.step, MIC5365-1.8YMT-TZ.step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]
2026-03-01 update pcb, cad, and code
    [1426.step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]
